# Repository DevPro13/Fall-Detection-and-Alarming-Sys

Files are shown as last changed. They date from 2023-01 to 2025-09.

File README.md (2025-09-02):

# Fall Detection and Alerting System

> "Fall seven times, stand up eight." - Japanese Proverb

While the proverb speaks of resilience, falls can be a critical health concern, especially for the elderly. This project presents a robust fall detection system that combines wearable technology and machine learning to provide timely alerts, mitigating the risks associated with delayed assistance.

This system is built upon the research detailed in the paper **"Fall Detection System for Elderly People Using LSTM"**. It leverages a custom-designed wearable device to monitor user movement and a sophisticated deep learning model to accurately distinguish between normal daily activities and dangerous falls.

The system is architecturally divided into two main sub-systems:
-   **Wearable Detector:** A compact, body-worn device that captures real-time motion data.
-   **System Groundstation:** A stationary unit that receives alerts from the wearable and triggers local alarms.

## System Activity Diagram
The operational flow of the system is as follows:
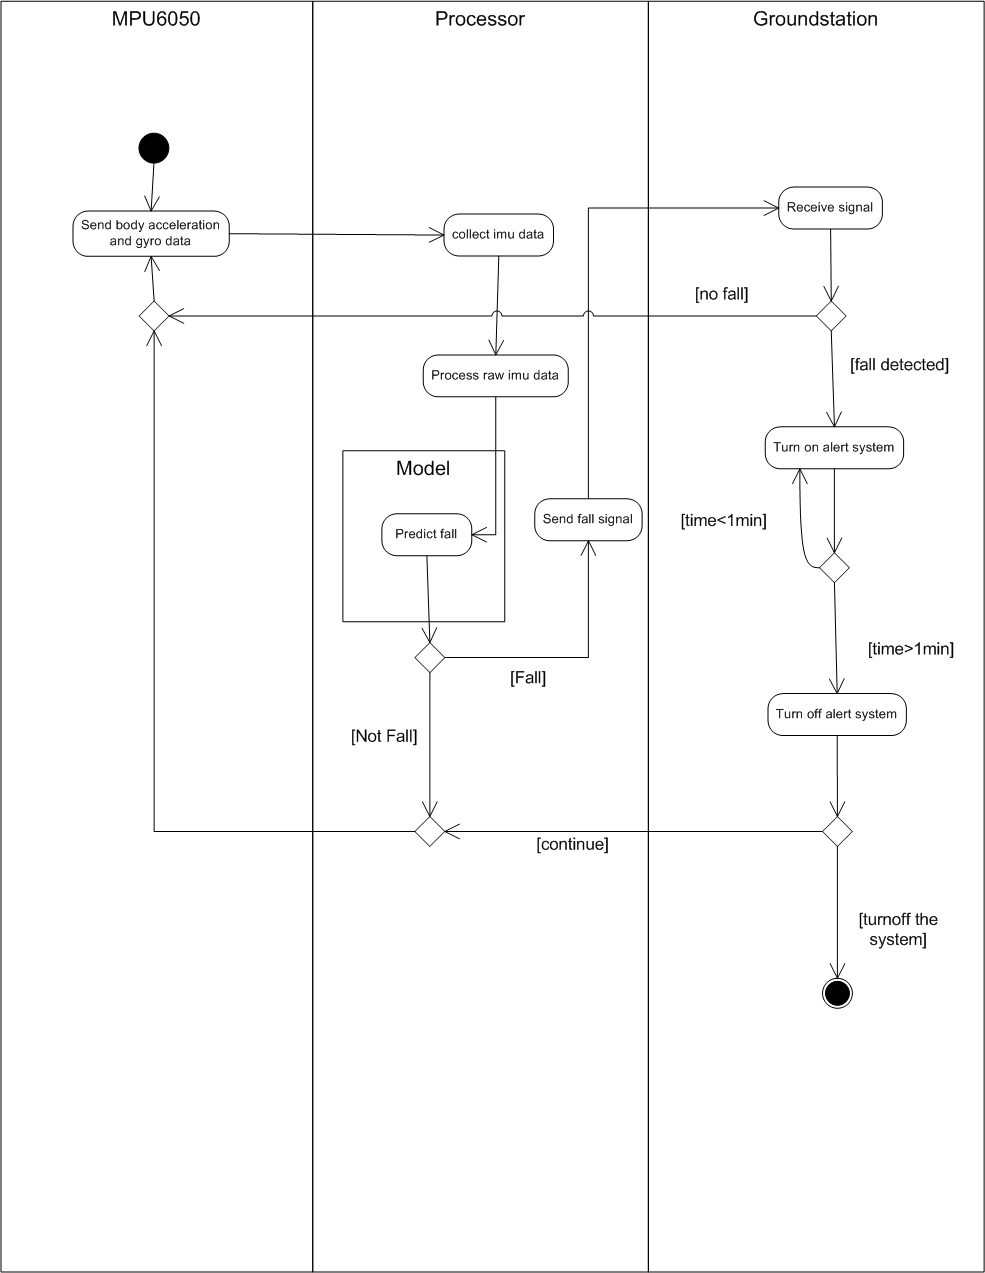
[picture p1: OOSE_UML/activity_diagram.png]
This is the Activity Diagram


## Wearable Detector

This is the core data acquisition and processing unit of the system. It is designed to be worn on the user's shoulder—a location chosen to minimize motion impedance and ensure stable, accurate readings. The device continuously captures motion data, processes it with an onboard machine learning model, and transmits an alert if a fall is detected.

**Key Components:**
*   **Microcontroller:** Raspberry Pi Pico (RP2040)
*   **Sensor:** MPU-6050, a 6-axis Inertial Measurement Unit (IMU) that provides accelerometer and gyroscope data.
*   **Wireless Communication:** The hardware is designed with a dedicated slot for an HC-05 Bluetooth module to transmit alerts wirelessly to the groundstation.
*   **Power Supply:** The device can be powered via a DC source (regulated by an LM7805 IC) or a direct USB connection.

### Machine Learning Model

The intelligence of the system lies in its fall detection model. Instead of simple thresholds, this project employs a **Long Short-Term Memory (LSTM)** neural network, a type of recurrent neural network (RNN) ideal for analyzing sequential data like human motion.

*   **Model Architecture:** The final system uses a refined **double-layer LSTM model**. This architecture proved significantly more effective than an initial single-layer model, demonstrating a superior ability to learn the complex temporal patterns that differentiate a fall from other activities.
*   **Data Collection:** The model was trained on a dataset created by capturing sequential motion data from participants mimicking the daily activities of the elderly (walking, sitting, standing) as well as simulated fall events.
*   **Performance:** The double-layer LSTM model achieved an impressive **accuracy of 97.8%**. More critically, it demonstrated high sensitivity in identifying falls, reducing the dangerous instances of false negatives that plagued simpler models.

| Metric | 1-Layer LSTM Model | 2-Layer LSTM Model |
| :--- | :--- | :--- |
| **Accuracy** | 92.19% | **97.8%** |
| **Sensitivity (Recall)** | 38.37% | **91.86%** |
| **Precision** | 75.00% | **87.78%** |
| **F1-Score** | 50.77% | **89.77%** |

The trained model is deployed directly onto the Raspberry Pi Pico, allowing for real-time, on-device inference without reliance on a constant internet connection.

### PCB Design
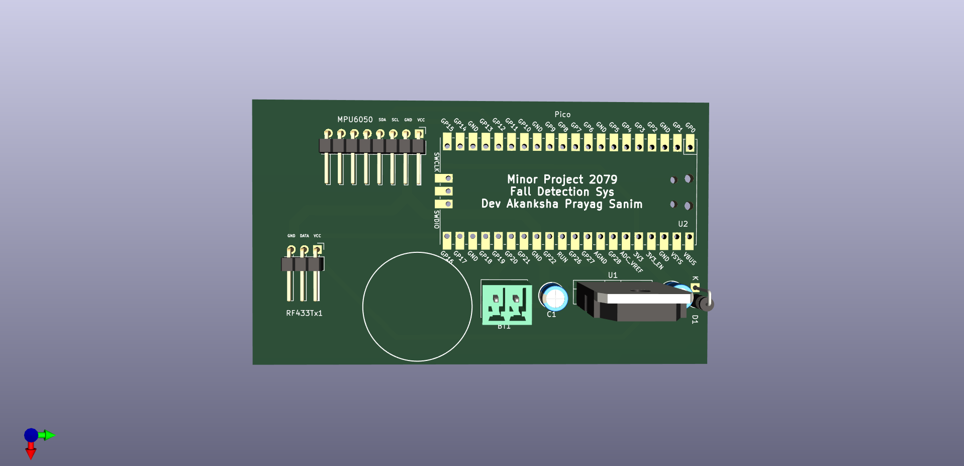
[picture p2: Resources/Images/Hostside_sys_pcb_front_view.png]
PCB of the wearable detector


## System Groundstation

The groundstation acts as the central alerting hub. It remains in a fixed location within the user's home, listening for signals from the wearable device. Upon receiving a fall alert, it triggers both audible and visual alarms to notify nearby caregivers.

**Key Components:**
*   **Microcontroller:** Atmega328p
*   **Wireless Communication:** An RF/Bluetooth receiver to communicate with the wearable device.
*   **Alerting Peripherals:** A loud buzzer and bright LEDs.
*   **Power Supply:** 5V DC power, supplied by the custom rectifier circuit below.

*(PCB image to be added)*

## Power Supply Rectifier

This custom circuit was designed to provide a stable, regulated 5V DC supply for the groundstation from an AC source.

**Components:**
*   Bridge Rectifier (Diodes)
*   LM7805 Voltage Regulator
*   Smoothing Capacitors
*   Resistor

### PCB Design
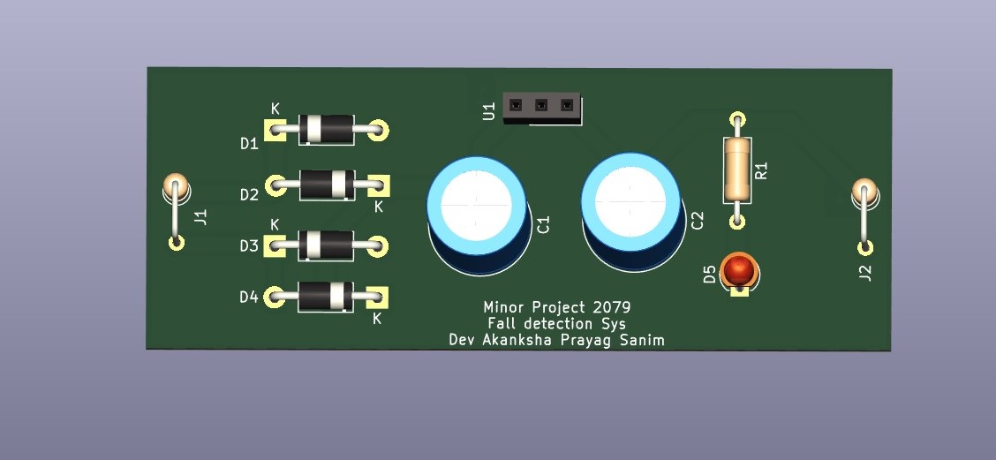
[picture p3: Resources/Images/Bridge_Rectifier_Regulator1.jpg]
PCB of the rectifier and regulator


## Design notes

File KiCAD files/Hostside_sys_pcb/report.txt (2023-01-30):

Info: Processing symbol 'BT1:Connector:JWT_A3963_1x02_P3.96mm_Vertical'.
Info: Processing symbol 'C1:Capacitor_THT:CP_Radial_D5.0mm_P2.00mm'.
Info: Processing symbol 'C2:Capacitor_THT:CP_Radial_D5.0mm_P2.00mm'.
Info: Processing symbol 'D1:Diode_SMD:D_SOD-123F'.
Info: Processing symbol 'MPU6050:Connector_PinHeader_2.54mm:PinHeader_1x08_P2.54mm_Horizontal'.
Info: Processing symbol 'RF433Tx1:Connector_PinHeader_2.54mm:PinHeader_1x03_P2.54mm_Horizontal'.
Info: Processing symbol 'U1:Package_TO_SOT_THT:TO-3P-3_Vertical'.
Info: Processing symbol 'U2:pipoco:RPi_Pico_SMD_TH'.
Changed MPU6050 footprint from 'Connector_PinHeader_2.54mm:PinHeader_1x08_P2.54mm_Vertical' to 'Connector_PinHeader_2.54mm:PinHeader_1x08_P2.54mm_Horizontal'.
Changed RF433Tx1 footprint from 'Connector_PinHeader_2.54mm:PinHeader_1x03_P2.54mm_Vertical' to 'Connector_PinHeader_2.54mm:PinHeader_1x03_P2.54mm_Horizontal'.
Warning: Via connected to unknown net ().
Warning: Via connected to unknown net ().

Info: Total warnings: 2, errors: 0.

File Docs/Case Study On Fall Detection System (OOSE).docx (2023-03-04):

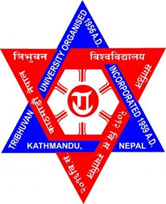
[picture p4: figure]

TRIBHUVAN UNIVERSITY
INSTITUTE OF ENGINEERING
PULCHOWK CAMPUS
DEPARTMENT OF
ELECTRONICS AND COMPUTER ENGINEERING

OOSE CASE STUDY REPORT ON
FALL DETECTION SYSTEM

A COURSE CASE STUDY REPORT SUBMITTED TO THE DEPARTMENT OF ELECTRONICS AND COMPUTER ENGINEERING IN FULFILLMENT OF THE REQUIREMENTS FOR THE PRACTICAL COURSE ON OBJECT ORIENTED SOFTWARE ENGINEERING [CT 657]

Submitted by
Akanksha Giri (076BEI004)
Devraj Parajuli (076BEI013)
Prayag Man Mane (076BEI027)
Sanim Kumar Khatri (076BEI037)

Submitted to
Asst. Prof. Santosh Giri
Department of Electronics and Computer Engineering
IOE, Pulchowk Campus

20th Falgun, 2079

TABLE OF CONTENT

1. FUNCTIONAL AND NON-FUNCTIONAL REQUIREMENTS 2

1.1 Functional requirements 2

Traceability Matrix 2

1.2 Non-functional requirements 3

2. UML USE CASE DIAGRAM 4

2.1 Diagram 4

2.2 Description 5

3. UML ACTIVITY DIAGRAM 7

3.1 Diagram 7

3.2 Description 8

4. UML SEQUENCE DIAGRAM 9

4.1 Diagram 9

4.2 Description 10

5. UML CLASS DIAGRAM 11

5.1 Diagram 11

LIST OF FIGURES

1. Use case diagram 4
2. Activity diagram 7
3. Sequence diagram 9
4. Class diagram 11

# 1. FUNCTIONAL AND NON-FUNCTIONAL REQUIREMENTS

## 1.1 Functional requirements

R.1: Detect Fall

Description: The model is used to predict fall situations based on the data processed by Pi Pico from the raw data obtained from the MPU6050 sensor.

R.1.1: Read acceleration and angular velocity data

- Input: Raw change in capacitance data from MPU6050
- Processing: Convert the raw data into relevant processable data using sensitivity and other constraints.
- Output: Processed 6-axis acceleration and gyroscope value

R.1.2: Predict Fall

- Input: Processed Acceleration and angular velocity data from MPU6050 sensor.
- Processing: Feed the input data into the ML model to get Fall/Not fall
- Output: Fall or Not Fall

R.2: Alert
Description: The RF modules establish the communication between transmitter

and Receiver. The Receiver decodes the encoded data received from the transmitter and rings the buzzer for one minute if the data it received is fall-detected data.

R.2.1: Alert

- Input: Fall Detected
- Output: Ring the buzzer

### Traceability Matrix

Req ID | 1.1 | 1.2 | 2.1
1.1
1.2 | U
2.1 | R | U

## 1.2 Non-functional requirements

R.1: Performance requirements

R.1.1: The raw data shall be processed in the model within 3 seconds.

R.1.2: After a fall is detected, alerting shall take no longer than 2 seconds.

R.2: Design Constraints

R.2.1: The System shall be developed using Python.

R.2.2: The collected data shall be logged in a CSV file.

R.3: Availability

R.3.1: The system shall be operated 24/7.

# 2. UML USE CASE DIAGRAM

## 2.1 Diagram

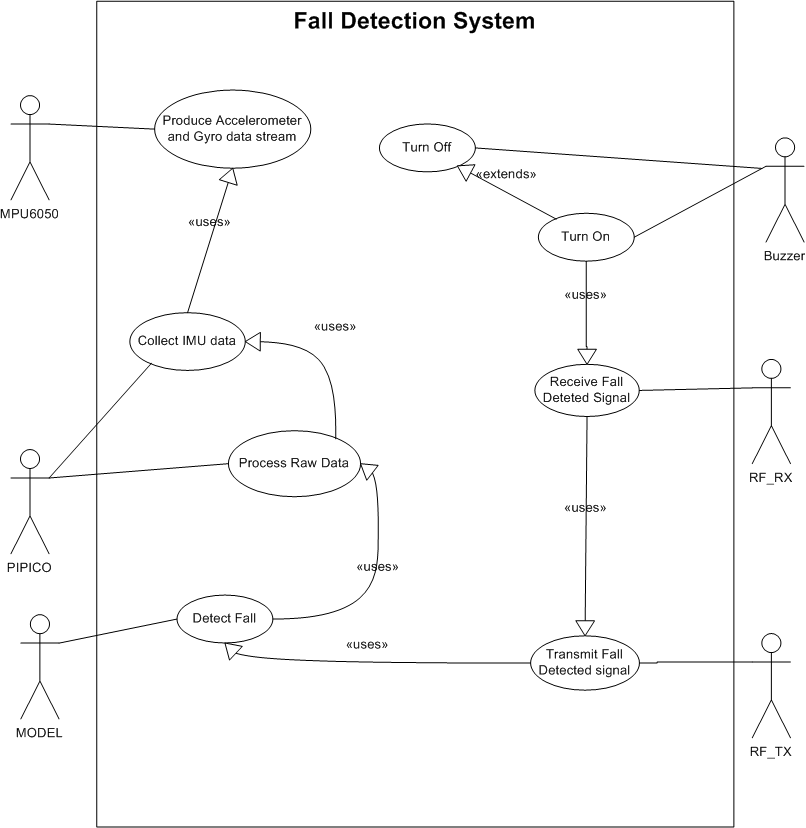
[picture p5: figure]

## 2.2 Description

Use case: Produce accelerometer and gyroscope data

Actors: MPU6050

Pre condition: The sensor should be powered

Post Condition: The sensor has produced accelerometer and gyroscope data

Description:

The sensor is activated and starts reading accelerometer and gyroscope data, which is measured by the physical movement and orientation of the user. The sensor sends it to the Raspberry-PiPico connected to it.

Use Case: Collect IMU data

Actors: PIPICO

Pre Condition: The board should be connected to the IMU via I2C interface

Description:

The board activates the I2C interface and initiates communication with the sensor. The board sends commands to the sensor and requests data. The board reads raw data sent by the sensor.

Use Case: Process Raw Data

Actors: PIPICO

Post Condition: The raw data has been processed to extract useful features for machine learning.

Description:

The raw data is processed to perform filtration, feature extraction, and calibration. The biases and offsets are corrected from the raw data. The data is transformed in a common range.

Use Case: Detect Fall

Actors: Model

Pre Condition: The sensor data is being collected and processed by the system

Post Condition: The system has detected a fall event and sent the signal to the RF module.

Description:

The system continuously monitors system data for significant change. The preprocessed data is passed to the machine learning model for analysis. The model analyzes the data to determine whether a fall event has occurred.

Use Case: Transmit detected signal

Actors: RF_TX

Pre Condition: The RF module is properly connected to the system and configured for communication.

Description:

The RF module encodes fall detected status from the model and transmits it.

Use Case: Receive detected signal

Actors: RF_RX

Description:

The RF module decodes the received signal into the relevant data.

Use Case: Turn On

Actors: Buzzer

Pre Condition: RF_RX received a fall detected signal.

Description:

The buzzer is powered on at a certain frequency for one minute.

Use Case: Turn Off

Actors: Buzzer

Pre Condition: Buzzer is turned on.

Description:

The buzzer is turned off after one minute of being powered on.

Overall overview of the use case diagram:

MPU6050 produces the accelerator and gyro data from its 3-axis capacitance values. Then the PIPICO collects the produced data from the MPU6050. After collecting the data, it processes the data into relevant values using sensitivity values and other constraints.
The model detects/predicts falls on the basis of the processed data from PIPICO, it is necessary to process the data to predict the fall.

The rf_tx transmits a fall detected signal if a fall is detected by the model. The rf_rx receives the fall detected signal if it is transmitted. Only when the signal is received the buzzer is turned on. Buzzer can be turned off if it has been turned on.

# 3. UML ACTIVITY DIAGRAM

## 3.1 Diagram


## 3.2 Description

The activity diagram begins with the MPU6050 sensor gathering body acceleration and gyroscope data. This raw data is then collected and processed by the Raspberry Pi Pico processor. Within the processor, a model generates a 'fall signal' based on the processed data to predict if a fall is imminent. This 'fall signal' is then continuously transmitted to the ground station for further analysis.

If the ground station detects a fall based on the 'fall signal', it activates the alert system. The alert signal remains active for one minute before turning off automatically. However, if the ground station does not detect a fall, no action is taken.

The product continuously monitors the body it is attached to, detecting potential falls until it is turned off. Overall, this system utilizes sensor data, processing power, and transmission capabilities to predict and detect falls, with a built-in alert system to notify others if a fall occurs.

# 4. UML SEQUENCE DIAGRAM

## 4.1 Diagram

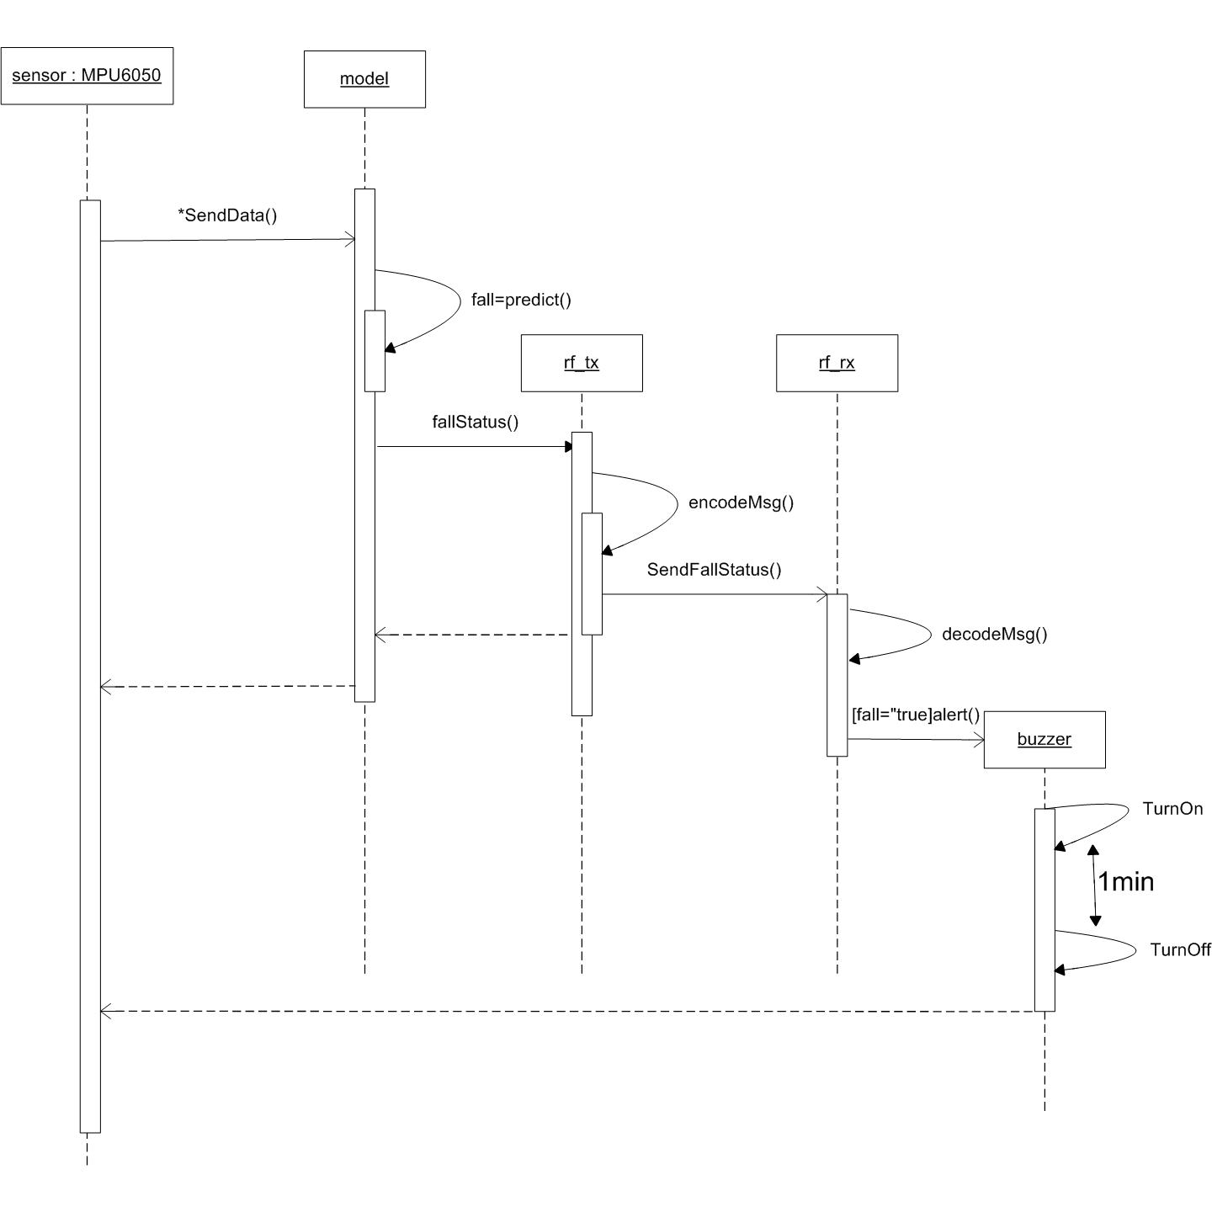
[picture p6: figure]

## 4.2 Description

The 6-axis accelerometer and gyroscope sends the data as a change in capacitance which is equivalent to some voltage level and the processor processes the raw data into relevant acceleration and gyro data which are the attributes of the object ‘sensor’ of class ‘MPU6050’. The ‘sensor’ sends the message SendData() to the model iteratively. In each iteration, the model predicts if the data signifies there is a fall or not.

The model then sends the status of the fall to the rf_tx and returns a message to the sensor so the sensor continues sending data iteratively. Then the rf_tx encodes the data itself and sends the sendfallstatus() message to rf_rx. The rf_rx sends a decode() message to itself. If the condition fall=’true’ is met, then the module creates a buzzer object.

The buzzer is turned on till 1 minute, when the time is exceeded the buzzer object is destroyed and the message is returned to the sensor object.

# 5. UML CLASS DIAGRAM

## 5.1 Diagram

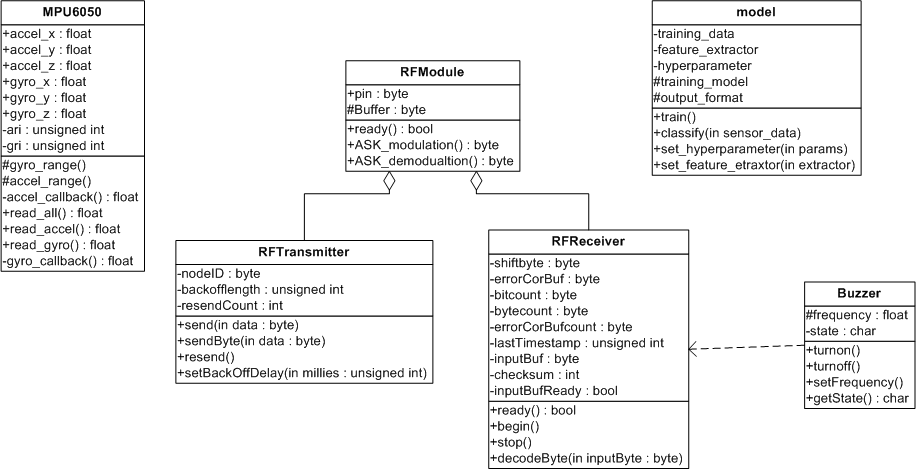
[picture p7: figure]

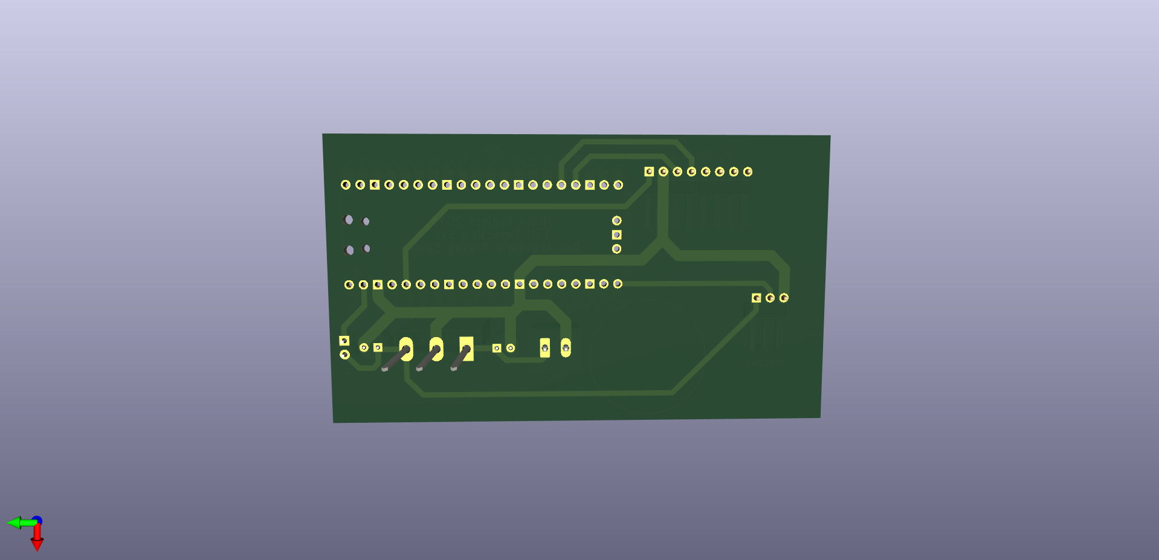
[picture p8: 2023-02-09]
Resources/Images/Hostside_sys_pcb_back_view.png

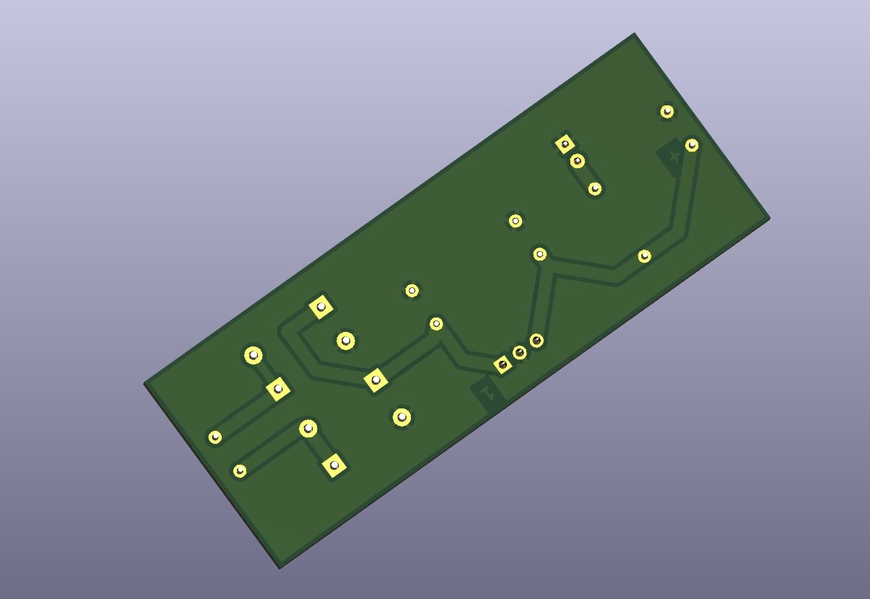
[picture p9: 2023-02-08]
Resources/Images/Bridge_Rectifier_Regulator2.jpg

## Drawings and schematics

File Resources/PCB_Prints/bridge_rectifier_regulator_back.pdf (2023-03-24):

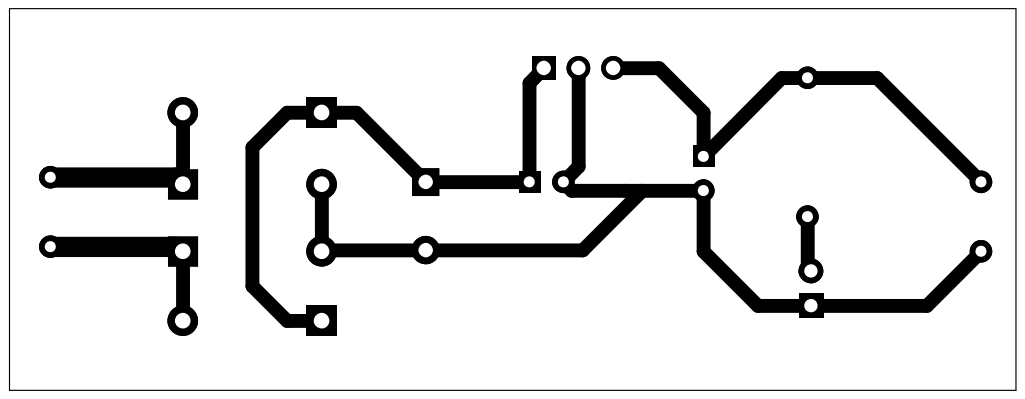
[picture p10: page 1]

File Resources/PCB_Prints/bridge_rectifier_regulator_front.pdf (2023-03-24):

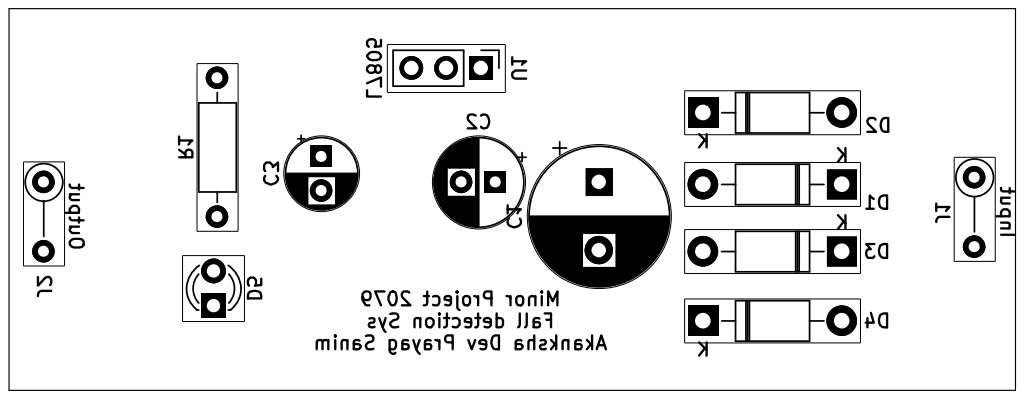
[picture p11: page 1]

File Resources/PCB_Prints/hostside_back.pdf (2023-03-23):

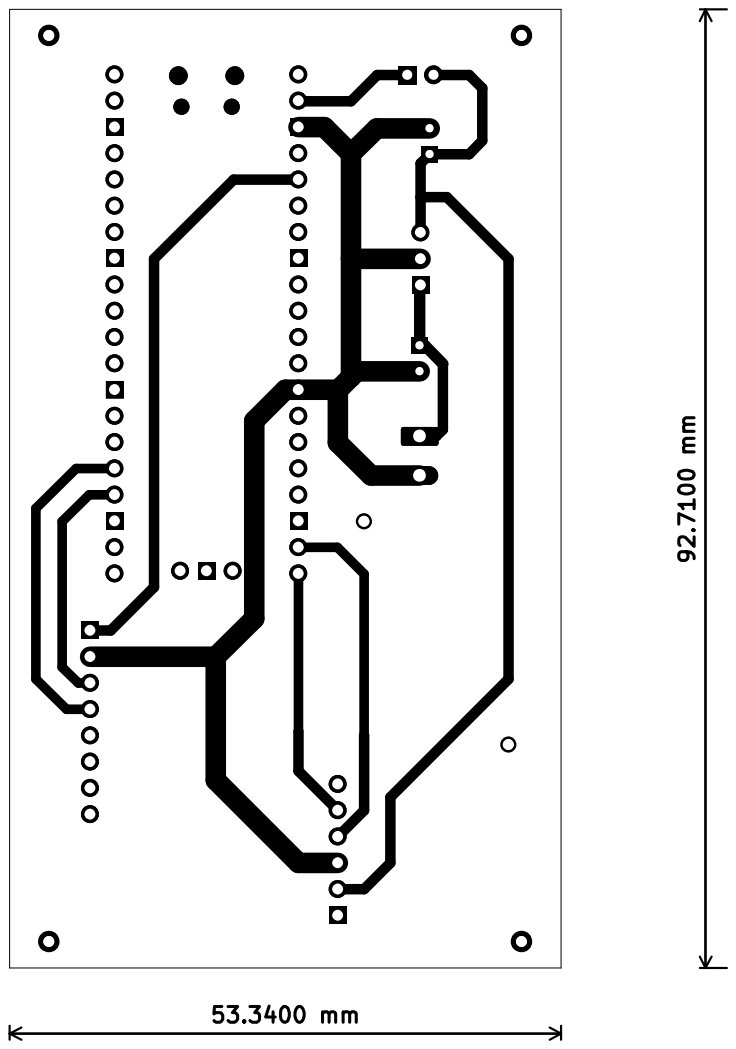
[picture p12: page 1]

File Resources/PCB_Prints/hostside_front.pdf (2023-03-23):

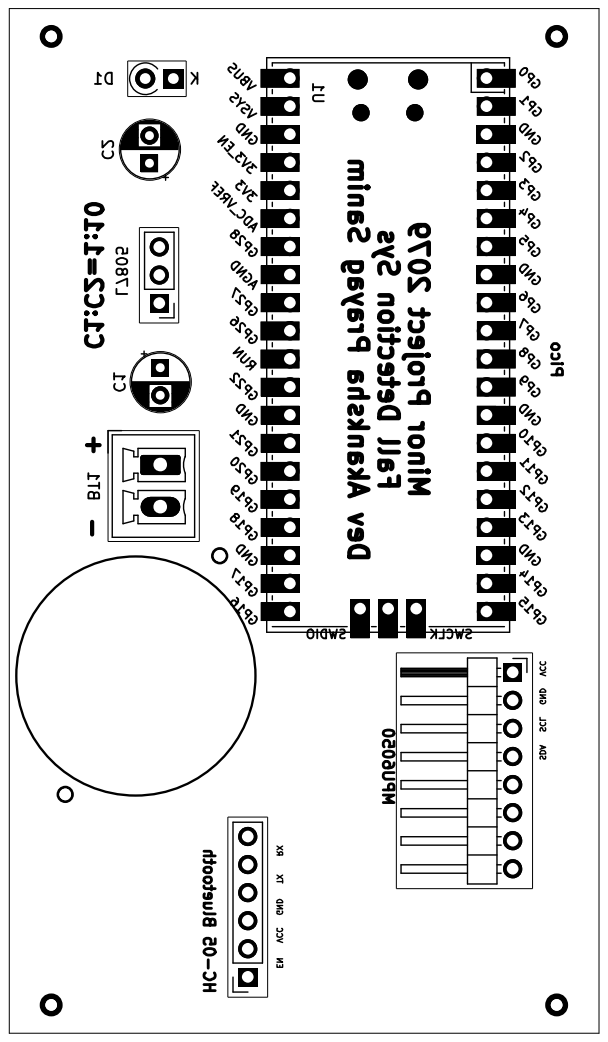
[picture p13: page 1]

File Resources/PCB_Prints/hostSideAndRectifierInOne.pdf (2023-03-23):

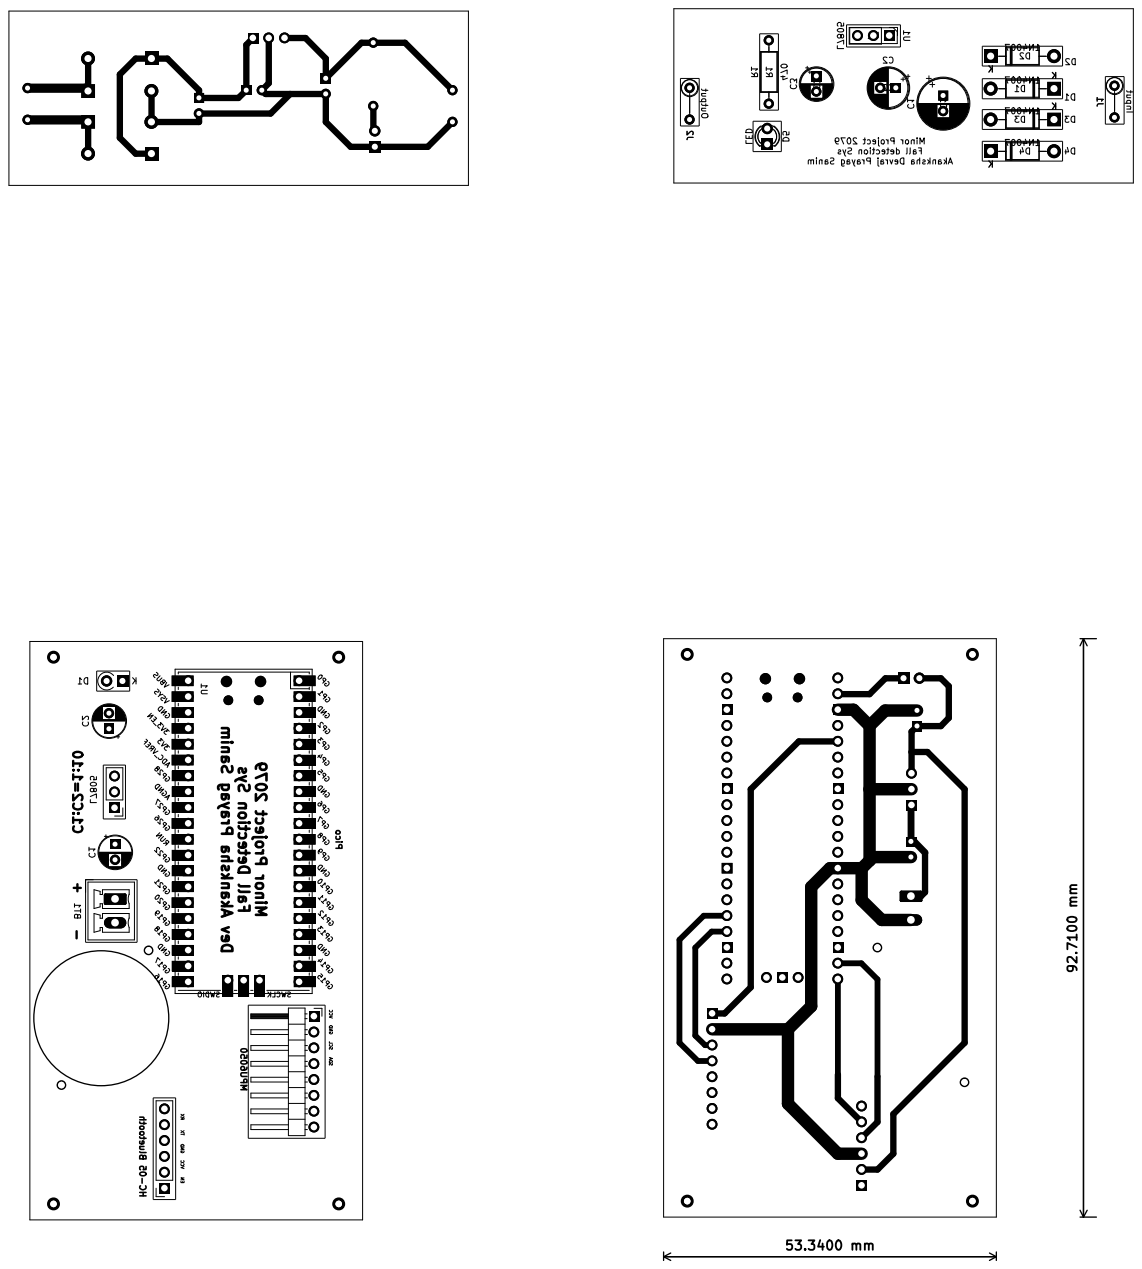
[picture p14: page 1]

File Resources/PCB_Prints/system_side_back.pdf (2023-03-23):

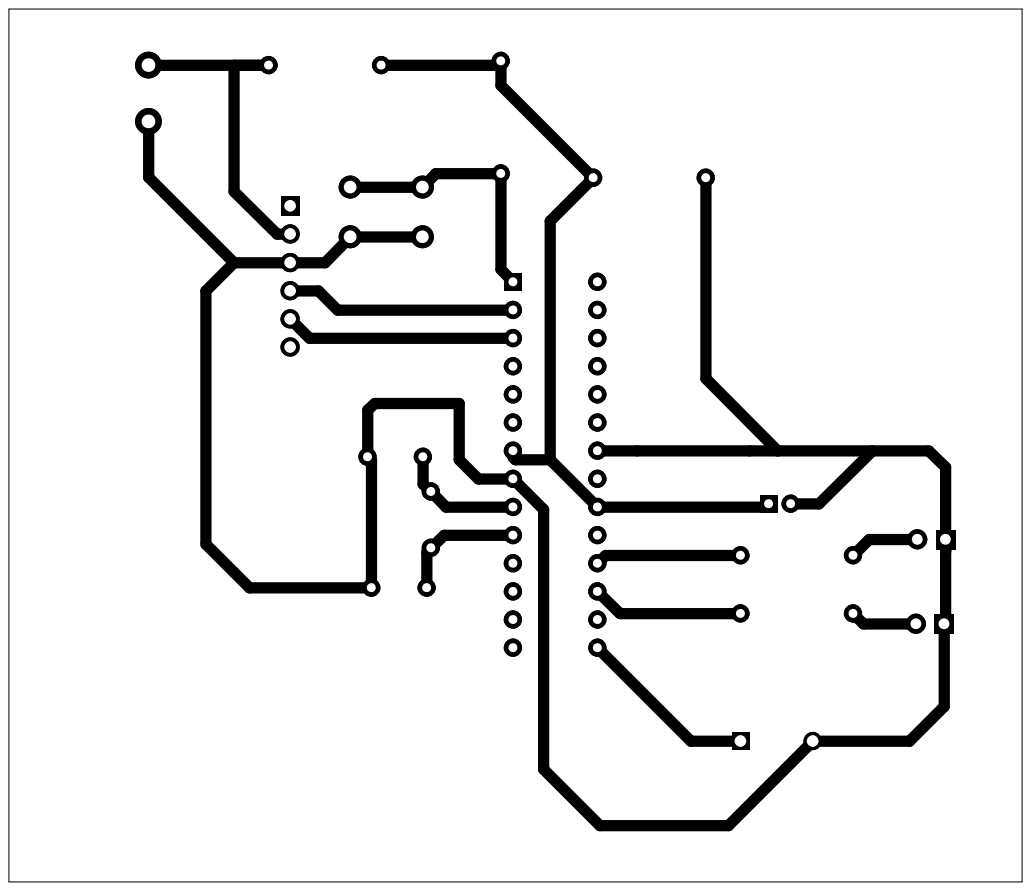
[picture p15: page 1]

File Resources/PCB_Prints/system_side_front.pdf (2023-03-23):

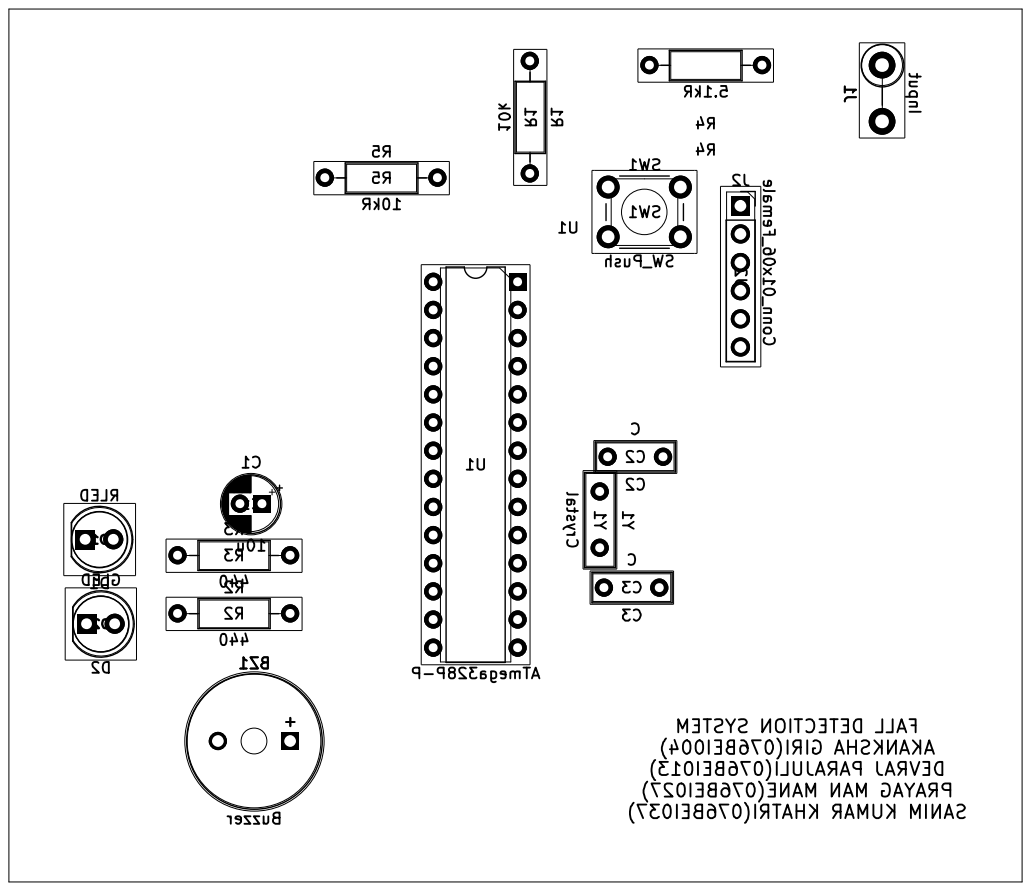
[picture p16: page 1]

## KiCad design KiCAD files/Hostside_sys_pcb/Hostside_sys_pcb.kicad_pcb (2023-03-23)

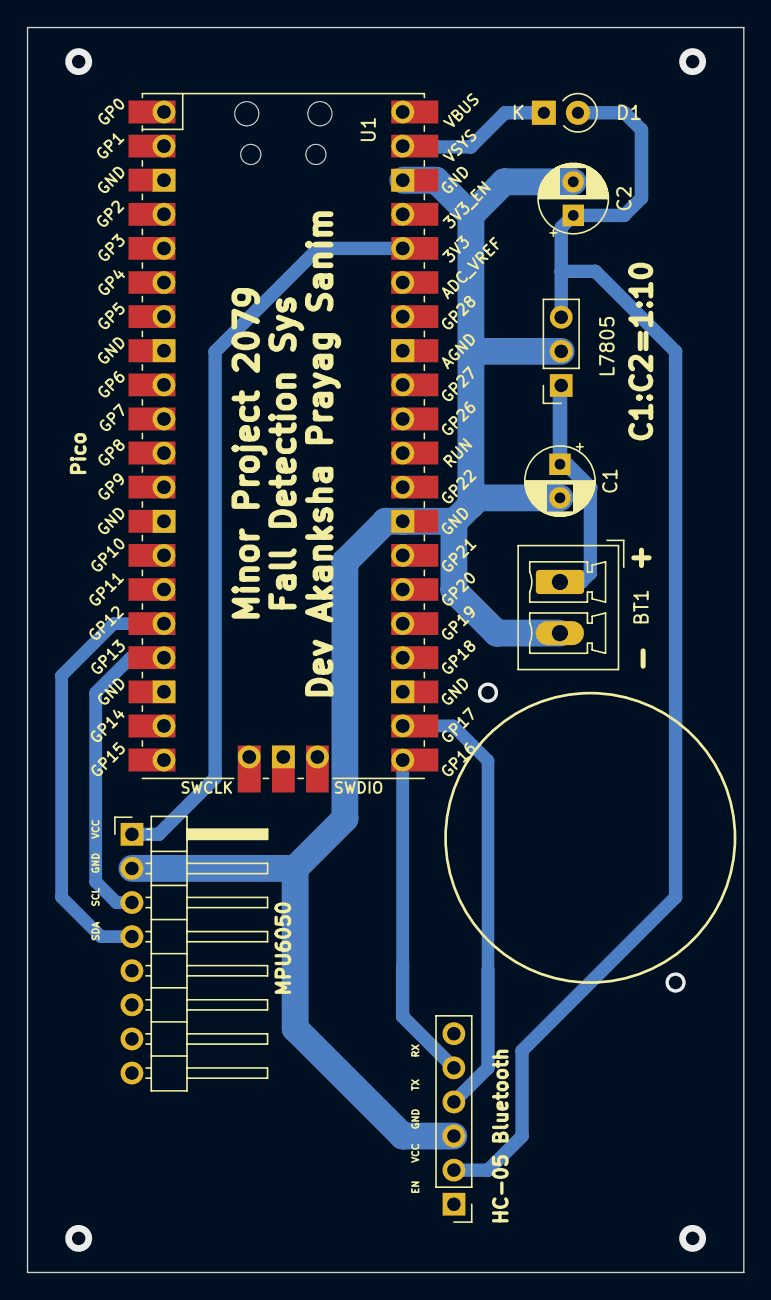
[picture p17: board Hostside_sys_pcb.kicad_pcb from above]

Board: 2 copper layers, 53.3 x 92.7 mm, 8 parts (0 on the bottom side), 9 nets.

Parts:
BT1: Battery_Cell; PhoenixContact_MCV_1,5_2-G-3.81_1x02_P3.81mm_Vertical
C1, C2: C; CP_Radial_D5.0mm_P2.50mm
D1: MBR1020VL; D_A-405_P2.54mm_Vertical_KathodeUp
HC-05 Bluetooth: Conn_01x06_Female; PinHeader_1x06_P2.54mm_Vertical
MPU6050: Conn_01x08_Female; PinHeader_1x08_P2.54mm_Horizontal
U1: Pico; RPi_Pico_SMD_TH
U2: L7805; PinSocket_1x03_P2.54mm_Vertical

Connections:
/SCL: MPU6050.3, U1.17 (GPIO13)
/SDA: MPU6050.4, U1.16 (GPIO12)
/VCC_3.3: MPU6050.1, U1.36 (3V3)
/Vin_5V: C2.1, D1.2 (A), HC-05 Bluetooth.2, U2.3 (OUT)
/rx: HC-05 Bluetooth.4, U1.22 (GPIO17)
/tx: HC-05 Bluetooth.5, U1.21 (GPIO16)
GND: BT1.2 (-), C1.2, C2.2, HC-05 Bluetooth.3, MPU6050.2, U1.28 (GND), U1.38 (GND), U2.2 (GND)
unnamed: BT1.1 (+), C1.1, U2.1 (IN)
unnamed: D1.1 (K), U1.39 (VSYS)

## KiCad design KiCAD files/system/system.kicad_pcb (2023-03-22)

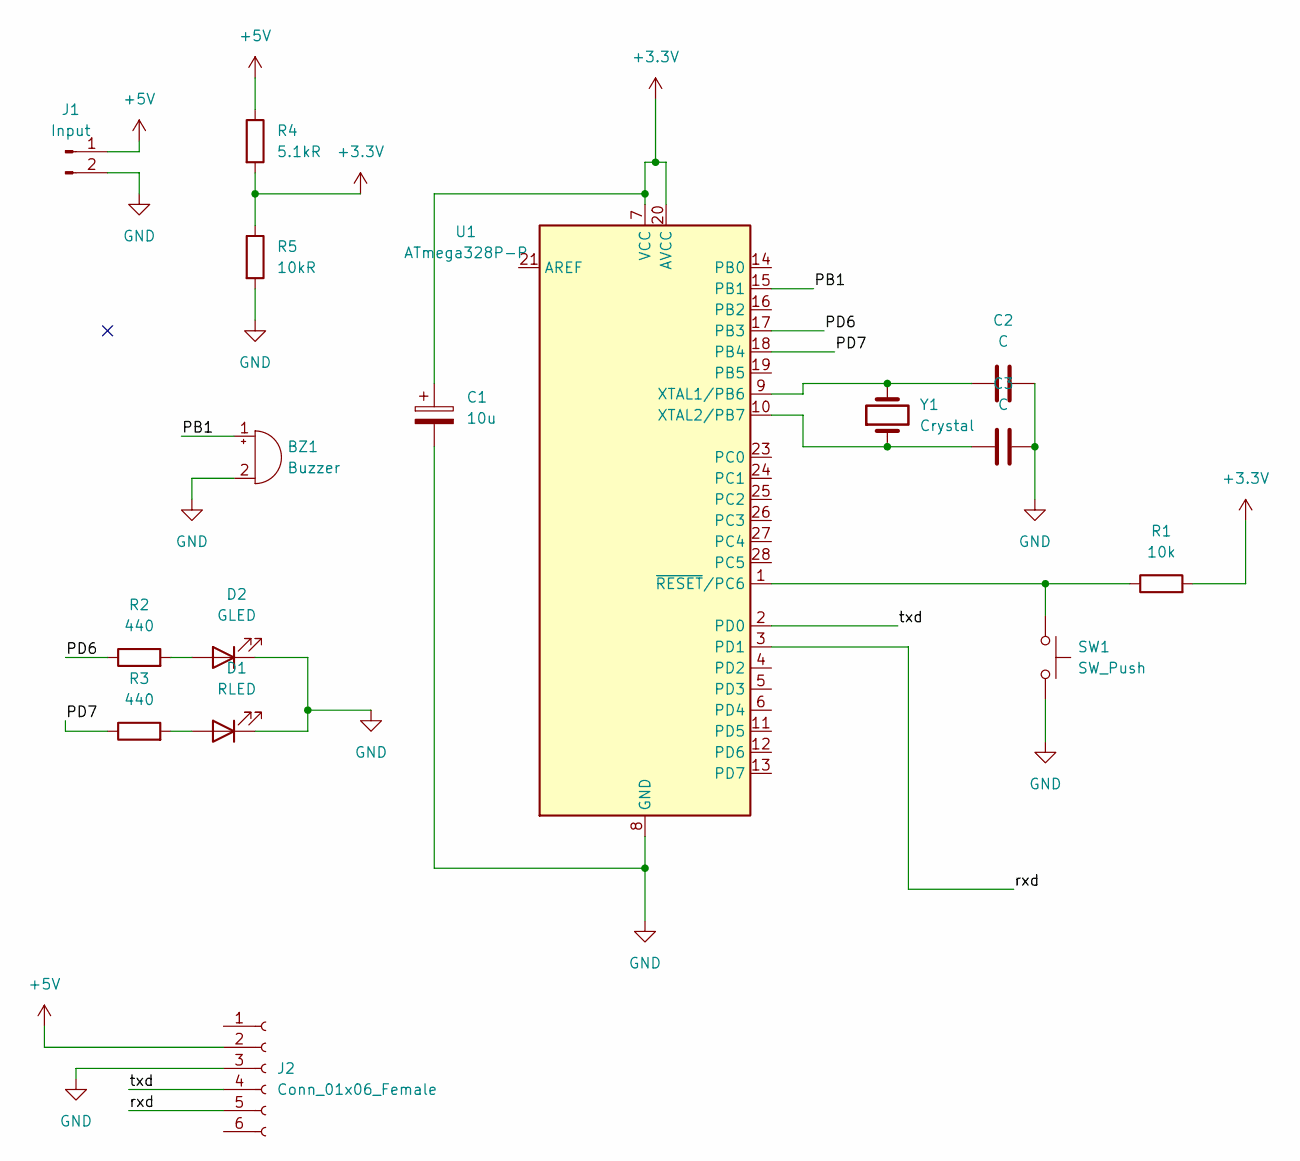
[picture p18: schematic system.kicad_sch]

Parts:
BZ1: Buzzer; MagneticBuzzer_ProSignal_ABT-410-RC
C1: 10u; CP_Radial_D5.0mm_P2.00mm
C2, C3: C; C_Disc_D7.0mm_W2.5mm_P5.00mm
D1: RLED; LED_D5.0mm
D2: GLED; LED_D5.0mm
J1: Input; R_Axial_DIN0411_L9.9mm_D3.6mm_P5.08mm_Vertical
J2: Conn_01x06_Female; PinHeader_1x06_P2.54mm_Vertical
R1: 10k; R_Axial_DIN0207_L6.3mm_D2.5mm_P10.16mm_Horizontal
R2, R3: 440; R_Axial_DIN0207_L6.3mm_D2.5mm_P10.16mm_Horizontal
R4: 5.1kR; R_Axial_DIN0207_L6.3mm_D2.5mm_P10.16mm_Horizontal
R5: 10kR; R_Axial_DIN0207_L6.3mm_D2.5mm_P10.16mm_Horizontal
SW1: SW_Push; SW_PUSH_6mm
U1: ATmega328P-P; DIP-28_W7.62mm
Y1: Crystal; R_Box_L8.4mm_W2.5mm_P5.08mm

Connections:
+3.3V: C1.1, R1.2, R4.2, R5.1, U1.7 (VCC), U1.20 (AVCC)
+5V: J1.1, J2.2, R4.1
/PB1: BZ1.1 (-), U1.15 (PB1)
/PD6: R2.1, U1.17 (PB3)
/PD7: R3.1, U1.18 (PB4)
/rxd: J2.5, U1.3 (PD1)
/txd: J2.4, U1.2 (PD0)
GND: BZ1.2 (+), C1.2, C2.2, C3.2, D1.1 (K), D2.1 (K), J1.2, J2.3, R5.2, SW1.2, U1.8 (GND), U1.22 (GND)
unnamed: C2.1, U1.9 (XTAL1/PB6), Y1.2
unnamed: C3.1, U1.10 (XTAL2/PB7), Y1.1
unnamed: D1.2 (A), R3.2
unnamed: D2.2 (A), R2.2
unnamed: R1.1, SW1.1, U1.1 (~RESET/PC6)

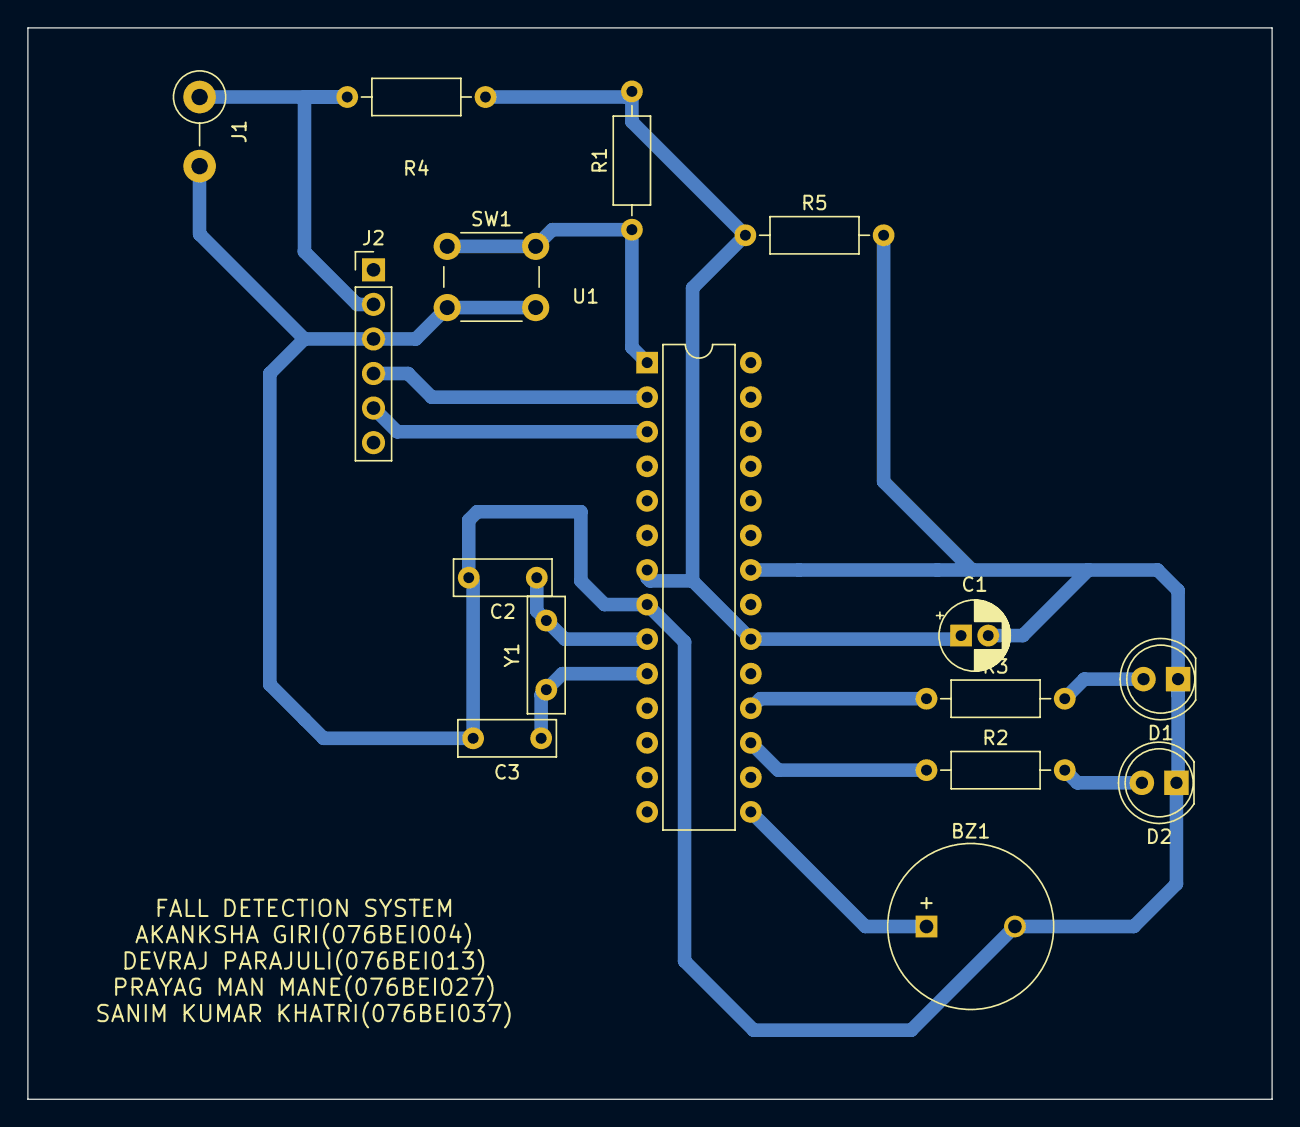
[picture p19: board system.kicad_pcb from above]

Board: 2 copper layers, 91.4 x 78.7 mm, 16 parts (0 on the bottom side), 13 nets.

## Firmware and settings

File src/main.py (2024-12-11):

###This code reads IMU sensors data and logs them in CSV file.###
import os
import time
from imu import MPU6050
from machine import Pin, I2C
i2c = I2C(0, sda=Pin(12), scl=Pin(13), freq=400000)
imu = MPU6050(i2c)
led=Pin(25,Pin.OUT)
imu.accel_range = 3    # set accelerometer sensitivity to +/- 16g
imu.gyro_range = 0	   # set gyroscope sensitivity to +/- 250 degrees/sec
def logData(data):
    with open("Data_Log.csv", "a") as file:
        first_char = file.read(1)
        print(not first_char)
        if not first_char:
            file.write("Epoch_time_s,milliseconds_elapsed,Ax,Ay,Az,Gx,Gy,Gz"+"\n") 
        data_in_text=",".join(str(data_item) for data_item in data)+"\n"
        file.write(data_in_text)
        file.flush() # flush data to the file        
if __name__=='__main__':
    for i in range(4):  #Blinks led before it starts reading sensors data
        led.value(i % 2)
        time.sleep(0.5)
    led.value(0)
    prev_tick=0
    time_in_ms=0#count time in milliseconds
    prev_epoch=0
    while True:
        ax=round(imu.accel.x,8)
        ay=round(imu.accel.y,8)
        az=round(imu.accel.z,8)
        gx=round(imu.gyro.x,8)
        gy=round(imu.gyro.y,8)
        gz=round(imu.gyro.z,8)
        current_time_in_epoch_s=time.time()#current
        current_tick=time.ticks_ms()#milliseconds elapsed
        tick_diff=abs(time.ticks_diff(prev_tick,current_tick))
        if prev_tick!=0:
            time_in_ms+=tick_diff
            if prev_epoch!=current_time_in_epoch_s:
                time_in_ms=0
            else:
                time_in_ms%=1000# value might exceed 1000 ms
        data=[current_time_in_epoch_s,time_in_ms,ax,ay,az,gx,gy,gz]
        #time starts from jan 1, 2021 12:00:00 AM
        print(data)
        logData(data)
        prev_tick=current_tick
        prev_epoch=current_time_in_epoch_s
        time.sleep(0.2)

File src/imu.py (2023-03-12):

'''
mpu9250 is a micropython module for the InvenSense MPU9250 sensor.
It measures acceleration, turn rate and the magnetic field in three axis.
mpu9150 driver modified for the MPU9250 by Peter Hinch

The MIT License (MIT)
Copyright (c) 2014 Sebastian Plamauer, oeplse@gmail.com, Peter Hinch
Permission is hereby granted, free of charge, to any person obtaining a copy
of this software and associated documentation files (the "Software"), to deal
in the Software without restriction, including without limitation the rights
to use, copy, modify, merge, publish, distribute, sublicense, and/or sell
copies of the Software, and to permit persons to whom the Software is
furnished to do so, subject to the following conditions:
The above copyright notice and this permission notice shall be included in
all copies or substantial portions of the Software.
THE SOFTWARE IS PROVIDED "AS IS", WITHOUT WARRANTY OF ANY KIND, EXPRESS OR
IMPLIED, INCLUDING BUT NOT LIMITED TO THE WARRANTIES OF MERCHANTABILITY,
FITNESS FOR A PARTICULAR PURPOSE AND NONINFRINGEMENT. IN NO EVENT SHALL THE
AUTHORS OR COPYRIGHT HOLDERS BE LIABLE FOR ANY CLAIM, DAMAGES OR OTHER
LIABILITY, WHETHER IN AN ACTION OF CONTRACT, TORT OR OTHERWISE, ARISING FROM,
OUT OF OR IN CONNECTION WITH THE SOFTWARE OR THE USE OR OTHER DEALINGS IN
THE SOFTWARE.
'''

# User access is now by properties e.g.
# myimu = MPU9250('X')
# magx = myimu.mag.x
# accelxyz = myimu.accel.xyz
# Error handling: on code used for initialisation, abort with message
# At runtime try to continue returning last good data value. We don't want aircraft
# crashing. However if the I2C has crashed we're probably stuffed.

from utime import sleep_ms
from machine import I2C
from vector3d import Vector3d


class MPUException(OSError):
    '''
    Exception for MPU devices
    '''
    pass


def bytes_toint(msb, lsb):
    '''
    Convert two bytes to signed integer (big endian)
    for little endian reverse msb, lsb arguments
    Can be used in an interrupt handler
    '''
    if not msb & 0x80:
        return msb << 8 | lsb  # +ve
    return - (((msb ^ 255) << 8) | (lsb ^ 255) + 1)


class MPU6050(object):
    '''
    Module for InvenSense IMUs. Base class implements MPU6050 6DOF sensor, with
    features common to MPU9150 and MPU9250 9DOF sensors.
    '''

    _I2Cerror = "I2C failure when communicating with IMU"
    _mpu_addr = (104, 105)  # addresses of MPU9150/MPU6050. There can be two devices
    _chip_id = 104

    def __init__(self, side_str, device_addr=None, transposition=(0, 1, 2), scaling=(1, 1, 1)):

        self._accel = Vector3d(transposition, scaling, self._accel_callback)
        self._gyro = Vector3d(transposition, scaling, self._gyro_callback)
        self.buf1 = bytearray(1)                # Pre-allocated buffers for reads: allows reads to
        self.buf2 = bytearray(2)                # be done in interrupt handlers
        self.buf3 = bytearray(3)
        self.buf6 = bytearray(6)

        sleep_ms(200)                           # Ensure PSU and device have settled
        if isinstance(side_str, str):           # Non-pyb targets may use other than X or Y
            self._mpu_i2c = I2C(side_str)
        elif hasattr(side_str, 'readfrom'):     # Soft or hard I2C instance. See issue #3097
            self._mpu_i2c = side_str
        else:
            raise ValueError("Invalid I2C instance")

        if device_addr is None:
            devices = set(self._mpu_i2c.scan())
            mpus = devices.intersection(set(self._mpu_addr))
            number_of_mpus = len(mpus)
            if number_of_mpus == 0:
                raise MPUException("No MPU's detected")
            elif number_of_mpus == 1:
                self.mpu_addr = mpus.pop()
            else:
                raise ValueError("Two MPU's detected: must specify a device address")
        else:
            if device_addr not in (0, 1):
                raise ValueError('Device address must be 0 or 1')
            self.mpu_addr = self._mpu_addr[device_addr]

        self.chip_id                     # Test communication by reading chip_id: throws exception on error
        # Can communicate with chip. Set it up.
        self.wake()                             # wake it up
        self.passthrough = True                 # Enable mag access from main I2C bus
        self.accel_range = 0                    # default to highest sensitivity
        self.gyro_range = 0                     # Likewise for gyro

    # read from device
    def _read(self, buf, memaddr, addr):        # addr = I2C device address, memaddr = memory location within the I2C device
        '''
        Read bytes to pre-allocated buffer Caller traps OSError.
        '''
        self._mpu_i2c.readfrom_mem_into(addr, memaddr, buf)

    # write to device
    def _write(self, data, memaddr, addr):
        '''
        Perform a memory write. Caller should trap OSError.
        '''
        self.buf1[0] = data
        self._mpu_i2c.writeto_mem(addr, memaddr, self.buf1)

    # wake
    def wake(self):
        '''
        Wakes the device.
        '''
        try:
            self._write(0x01, 0x6B, self.mpu_addr)  # Use best clock source
        except OSError:
            raise MPUException(self._I2Cerror)
        return 'awake'

    # mode
    def sleep(self):
        '''
        Sets the device to sleep mode.
        '''
        try:
            self._write(0x40, 0x6B, self.mpu_addr)
        except OSError:
            raise MPUException(self._I2Cerror)
        return 'asleep'

    # chip_id
    @property
    def chip_id(self):
        '''
        Returns Chip ID
        '''
        try:
            self._read(self.buf1, 0x75, self.mpu_addr)
        except OSError:
            raise MPUException(self._I2Cerror)
        chip_id = int(self.buf1[0])
        if chip_id != self._chip_id:
            raise ValueError('Bad chip ID retrieved: MPU communication failure')
        return chip_id

    @property
    def sensors(self):
        '''
        returns sensor objects accel, gyro
        '''
        return self._accel, self._gyro

    # get temperature
    @property
    def temperature(self):
        '''
        Returns the temperature in degree C.
        '''
        try:
            self._read(self.buf2, 0x41, self.mpu_addr)
        except OSError:
            raise MPUException(self._I2Cerror)
        return bytes_toint(self.buf2[0], self.buf2[1])/340 + 35  # I think

    # passthrough
    @property
    def passthrough(self):
        '''
        Returns passthrough mode True or False
        '''
        try:
            self._read(self.buf1, 0x37, self.mpu_addr)
            return self.buf1[0] & 0x02 > 0
        except OSError:
            raise MPUException(self._I2Cerror)
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

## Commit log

2023-01-15 Added gitignore file and simulation
    simulation of bridge rectifier and regulator
    [bridge_rectifier_regulator.DSN]
2023-01-15 Bridge rectifier (KiCAD) added
    [RectifierAndRegulator.kicad_pcb, RectifierAndRegulator.kicad_sch]
2023-01-15 Added resources
    For bridge rectifier and regulator
2023-01-30 Host side PCB design files added
    [Hostside_sys_pcb.kicad_pcb, Hostside_sys_pcb.kicad_sch]
2023-02-03 started system side pcb
    this is initial phase, more updates are needed on this pcb
    [system.kicad_pcb, system.kicad_sch]
2023-02-08 Edited Rectifier schematics and PCB
    edited the trackwidth from 1mm to 1.5mm
    [RectifierAndRegulator.kicad_pcb, RectifierAndRegulator.kicad_sch]
2023-02-08 Edited system schematics
    [system.kicad_pcb, system.kicad_sch]
2023-02-08 Edited PCB
    [RectifierAndRegulator.kicad_pcb]
2023-02-08 Hostside pcb front and back images and PCB_prints pdf files added into resources
2023-02-08 host side kicad files added and updated
    [Hostside_sys_pcb.kicad_pcb, Hostside_sys_pcb.kicad_sch]
2023-02-08 hostside_front pcb_print made mirrored and added
2023-02-08 tracks between distance updated for scl and sda lines and capacitor pin size updated and pcb_ prints pdf files added
2023-02-08 Hostside kicad files updated and added
    [Hostside_sys_pcb.kicad_pcb, Hostside_sys_pcb.kicad_sch]
2023-02-09 Rectiier ckt bug fixed
    [RectifierAndRegulator.kicad_pcb, RectifierAndRegulator.kicad_sch, system.kicad_pcb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]
2023-02-09 Edited rectifier pcb
    [RectifierAndRegulator.kicad_pcb]
2023-02-09 clearance updated in hostside pcb
    [Hostside_sys_pcb.kicad_pcb, Hostside_sys_pcb.kicad_sch]
2023-02-16 Edited system pcb layout
    [system.kicad_pcb, system.kicad_sch]
2023-02-16 Update schematics of system
    [system.kicad_pcb, system.kicad_sch]
2023-03-04 use case diagram added
2023-03-04 Use case and Sequence diagram added
2023-03-04 Edited use case diagram
2023-03-04 Case study documents on Fall detection system added
2023-03-08 edited oops
    [Hostside_sys_pcb.kicad_sch, RectifierAndRegulator.kicad_sch]
2023-03-09 edited the system side circuit
    [system.kicad_pcb, system.kicad_sch]
2023-03-12 New Dataset files added
    [system.kicad_pcb, system.kicad_sch]
2023-03-12 new dataset added
    [datalog_fall_data.csv, datalog_normal_state_data.csv, datalog_run_data.csv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]
2023-03-18 edited system side pcb
    [system.kicad_pcb, system.kicad_sch]
2023-03-22 edited system pcb
    [system.kicad_pcb, system.kicad_sch]
2023-03-22 final draft of the system side pcb
    [system.kicad_pcb]
2023-03-22 halka edit smoothing capacitor ma
    [RectifierAndRegulator.kicad_pcb, RectifierAndRegulator.kicad_sch, bridge_rectifier_regulator.DSN]
2023-03-23 edited the print images
2023-03-23 print images added for system
2023-03-23 Host side pcb updates
    [Hostside_sys_pcb.kicad_pcb, Hostside_sys_pcb.kicad_sch]
2023-03-23 edited size of capacitor footprint
    [RectifierAndRegulator.kicad_pcb, RectifierAndRegulator.kicad_sch]
2023-03-23 files merge
    [Hostside_sys_pcb.kicad_pcb, RectifierAndRegulator.kicad_pcb]
2023-03-24 updated the pdf of pcb
    [RectifierAndRegulator.kicad_pcb]
2023-03-24 rectifier pcb prints update
    [RectifierAndRegulator.kicad_pcb]
2024-12-06 Dataset for LSTM added.
    [person1_session1.csv, person1_session2.csv, person1_session3.csv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]
2024-12-11 Bug fixed: Issue regarding data logging and elapsed time.
    [main.py]
2024-12-11 Removed Dataset
    [person1_session1.csv, person1_session2.csv, person1_session3.csv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]
